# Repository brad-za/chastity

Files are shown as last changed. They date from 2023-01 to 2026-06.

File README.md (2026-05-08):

# Chastity Keyboard - Choc v1

A wireless split ergonomic keyboard featuring Kailh Choc v1 low-profile switches, rotary encoders, and ZMK firmware.

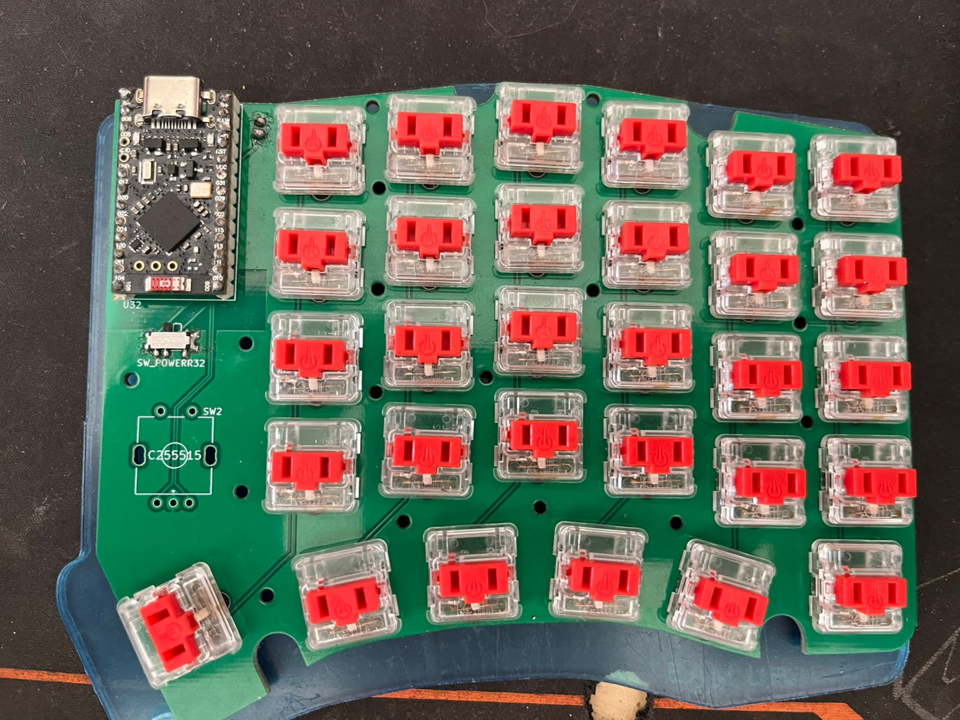
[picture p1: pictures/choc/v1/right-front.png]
Chastity Keyboard_ChocV1


## Features

- **Split Design**: Ergonomic 30-key split layout per half (60 keys total)
- **Wireless**: Powered by nice!nano v2 controllers with ZMK firmware
- **Low Profile**: Kailh Choc v1 switches for a sleek, portable design
- **Rotary Encoders**: One encoder per half for volume/scroll control
- **Hot-swap**: Choc v1 hot-swap sockets for easy switch replacement
- **Battery Powered**: Individual LiPo batteries for each half
- **Power Management**: Individual power switches per half

## Bill of Materials (BOM)

### Electronics & Controllers
| Component | Quantity | Description | Notes |
|---|---|---|---|
| nice!nano v2 | 2 | Wireless microcontroller | One per half |
| LiPo Battery | 2 | 3.7V 110-301230 or similar | ~110mAh recommended |
| JST PH 2-pin Connector | 2 | Battery connector | For nice!nano battery connection |

### Switches & Keycaps
| Component | Quantity | Description | Notes |
|---|---|---|---|
| Kailh Choc v1 Switches | 60 | Low-profile mechanical switches | Any Choc v1 variant |
| Choc v1 Keycaps (1u) | 54 | Standard 1u keycaps | |
| Choc v1 Keycaps (1u) | 2 | Indexed 1u keycaps | F & J keys |
| Choc v1 Keycaps (1.25u) | 2 | Pinky key keycaps | For control buttons cluster |
| Choc v1 Keycaps (1.5u) | 2 | Thumb key keycaps | For thumb cluster |

### Electronic Components
| Component | Quantity | Description | Package | Notes |
|---|---|---|---|---|
| Diodes | 60 | 1N4148W or similar | SOD-123 | One per switch |
| Rotary Encoder | 2 | Alps EC11E series | Through-hole | With push switch |
| Power Switch | 2 | SPDT slide switch | PCM12 package | Individual power control |
| Choc v1 Hot-swap Sockets | 60 | Kailh hot-swap sockets | | One per switch position |

### PCBs & Hardware
| Component | Quantity | Description | Notes |
|---|---|---|---|
| Chastity PCB Left | 1 | Main PCB for left half | Fabricate from KiCad files |
| Chastity PCB Right | 1 | Main PCB for right half | Fabricate from KiCad files |
| Case Components | 1 set | Laser-cut case files | Optional - see cases/choc/v1/ |

### Optional Components
| Component | Quantity | Description | Notes |
|---|---|---|---|
| USB-C Cable | 2 | Charging/programming | Standard USB-C cables |

## Assembly Instructions

### 1. PCB Preparation
1. Inspect PCBs for any manufacturing defects
2. Clean flux residue if necessary

### 2. SMD Component Soldering
1. **Diodes**: Solder all 60 diodes (30 per PCB) in SOD-123 packages
   - Pay attention to polarity markings on the PCB
   - Cathode (marked end) should align with the line on the PCB silkscreen

### 3. Through-hole Components
1. **Hot-swap sockets**: Install all 60 Choc v1 hot-swap sockets
   - Ensure proper alignment before soldering
   - Apply flux for clean joints
2. **Rotary encoders**: Install one Alps EC11E encoder per PCB
   - Ensure proper seating before soldering
3. **Power switches**: Install PCM12 slide switches
4. **Battery connectors**: Install JST PH 2-pin connectors

### 4. Controller Installation
1. **Socket installation** (recommended):
   - Install mill-max sockets for nice!nano controllers
   - This allows for easy removal/replacement
2. **nice!nano mounting**:
   - Install nice!nano v2 controllers with components facing down
   - Ensure proper pin alignment

### 5. Switch Installation
1. Install Kailh Choc v1 switches into hot-swap sockets
2. Ensure switches are fully seated and secure
3. Test each switch for proper actuation

### 6. Keycap Installation
1. Install keycaps on all switches
2. Use 1.25u keycaps for thumb cluster keys

## Firmware

This keyboard uses ZMK firmware with configurations located in `code/zmk/`.

### Flashing Firmware

#### Initial Setup
1. Connect nice!nano via USB-C
2. Put controller in bootloader mode (double-tap reset)
3. Flash the appropriate firmware:
   - `chastity_left-nice_nano_v2-zmk.uf2` for left half
   - `chastity_right-nice_nano_v2-zmk.uf2` for right half

#### Building Custom Firmware
1. Fork the ZMK config repository
2. Modify keymap in `config/chastity.keymap`
3. GitHub Actions will automatically build firmware
4. Download and flash the generated `.uf2` files

### Keymap Configuration

The keymap lives at `code/zmk/boards/shields/chastity/chastity.keymap`. Four layers are defined:

| # | Name | Purpose |
|---|---|---|
| 0 | DEFAULT  | QWERTY base layer. |
| 1 | NUMPAD | F-keys on the top row, numpad cluster on the right hand, shifted-symbol cluster on the left. Toggle with `tog NUMPAD`. |
| 2 | NAV | Caps Lock + media controls on the top-left, arrow / Home / End cluster on the right hand, **Bluetooth controls on the top-right row**. Toggle with `tog NAV`. |
| 3 | GAMING | Shifts the left half one column to the right so physical WASD outputs ESDF; the now-blank inner column gets right-side letters (P / L / M / O / I / U) so the right hand isn't needed while gaming. Toggle with the chord **RCTRL + RET (right thumb) + P**. |

#### Encoders

| Encoder | Rotation | Press (matrix-shared with the inner thumb key) |
|---|---|---|
| Left | Mouse scroll wheel up / down | `F24` — useful for binding push-to-talk or stream macros |
| Right | Volume up / down | `C_MUTE` |

The encoder press position shares its matrix net with the inner-thumb key on each half — so pressing the inner thumb fires the same key as the encoder click.

#### Bluetooth controls (on NAV layer, top-right row, inner → outer)

```
out OUT_TOG | bt BT_SEL 0 | bt BT_SEL 1 | bt BT_SEL 2 | bt BT_SEL 3 | bt BT_CLR
```

- `OUT_TOG` toggles output between USB and BLE
- `BT_SEL 0..3` switches between four paired hosts
- `BT_CLR` clears the bond on the currently selected profile (use this to re-pair). Placed at the outer edge so it isn't pressed by accident.

#### BLE name

The keyboard advertises as **`Chastity`** (set in `Kconfig.defconfig`). The right half advertises as `Chastity Right` to the central only — your host never sees it.

## Case Options

Case files are available in the `cases/choc/v1/` directory:
- `chastity-bottom-left.dxf` / `chastity-bottom-right.dxf` - Bottom plates
- `chastity-bb-left.dxf` / `chastity-bb-right.dxf` - Switch plates

### Case Assembly
1. Laser cut case components from 3mm acrylic or similar
2. Use M3 standoffs and screws for assembly
3. Install rubber feet for stability

## Suppliers & Part Numbers

### Electronics
- **nice!nano v2**: [Typeractive](https://typeractive.xyz/products/nice-nano), [splitkb.com](https://splitkb.com)
- **Batteries**: Search for "110mAh 3.7V LiPo" on electronics suppliers
- **Diodes**: 1N4148W from Digikey, Mouser, LCSC
- **Encoders**: Alps EC11E15244G1 or similar

### Mechanical Components
- **Choc v1 Switches**: [NovelKeys](https://novelkeys.com), [splitkb.com](https://splitkb.com)
- **Choc Keycaps**: [MBK keycaps](https://mkultra.click/mbk-choc-keycaps), [splitkb.com](https://splitkb.com)
- **Hot-swap Sockets**: Kailh Choc v1 sockets from mechanical keyboard suppliers

### PCB Fabrication
Upload the Gerber files from `kicad/choc/v1/` to:
- **JLCPCB**: Cost-effective option
- **PCBWay**: Good quality and service
- **OSH Park**: US-based, high quality

## Troubleshooting

### Common Issues
1. **Switch not registering**: Check diode polarity and solder joints
2. **Encoder not working**: Verify encoder orientation and pin connections
3. **Battery not charging**: Check JST connector polarity and nice!nano installation
4. **Wireless connection issues**: Re-pair devices, check ZMK configuration

### Support
- Check ZMK documentation: [zmk.dev](https://zmk.dev)
- Review schematic files in `kicad/choc/v1/`
- Verify component placement against PCB silkscreen

## License

This project is open source. PCB designs, case files, and firmware configurations are available for personal and educational use.

## Changelog

### v1.0
- Initial release with Choc v1 support
- ZMK firmware configuration
- Complete build documentation

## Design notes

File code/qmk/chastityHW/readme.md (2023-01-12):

# chastity

chastity

*A short description of the keyboard/project*

* Keyboard Maintainer: [streetRAT](https://github.com/yourusername)
* Hardware Supported: *The PCBs, controllers supported*
* Hardware Availability: *Links to where you can find this hardware*

Make example for this keyboard (after setting up your build environment):

    make chastity:default

Flashing example for this keyboard:

    make chastity:default:flash

See the [build environment setup](https://docs.qmk.fm/#/getting_started_build_tools) and the [make instructions](https://docs.qmk.fm/#/getting_started_make_guide) for more information. Brand new to QMK? Start with our [Complete Newbs Guide](https://docs.qmk.fm/#/newbs).

## Bootloader

Enter the bootloader in 3 ways:

* **Bootmagic reset**: Hold down the key at (0,0) in the matrix (usually the top left key or Escape) and plug in the keyboard
* **Physical reset button**: Briefly press the button on the back of the PCB - some may have pads you must short instead
* **Keycode in layout**: Press the key mapped to `RESET` if it is available

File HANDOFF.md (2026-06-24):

# Chastity v1 Keyboard — Firmware Debug Handoff

**Status: keyboard is unusable. Multiple symptoms, multiple failed fix attempts. Previous agent chased symptoms, did not pin down root causes. Hand-off written 2026-05-08 by previous agent who is being fired by the user.**

---

## Read me first

You are picking up a partially-failed debug session. The previous agent (me) made things worse over the course of ~6 hours of iteration. The user is exhausted, angry, and rightly out of patience. They want **root-cause analysis with verification**, not more guessing.

**Before you change a single config file:**
1. Read this entire document
2. Run the verification commands at the bottom to confirm current build state
3. Run the **hardware diagnostic checklist** in §6 — most of those should have been done before any firmware edits
4. Only then propose changes, and verify the *built artifacts* (not just the source) before asking the user to flash

The user has explicitly said "stop fixing symptoms and find the cause." Do that.

---

## §1. Hardware context

- **Board**: chastity v1 split keyboard (choc switches), user-designed PCB
- **Controllers**: 2× nice!nano v2 (nRF52840), one per half
- **Diodes**: installed **backwards by mistake** during assembly. Firmware compensates via `diode-direction = "col2row"` (NOT the upstream `row2col`). User confirmed this verbally — do not suggest reverting the direction.
- **User-verified hardware facts** (per multimeter): continuity is consistent across both halves, diodes orient consistently. User had one of two pro micros that performed worse — swap to the other did not fix anything, ruling out single-MCU damage.

### Pin layout (right half — `chastity_right.overlay`)

| Net | GPIO | nRF52840 pin | Notes |
|---|---|---|---|
| C0 (encoder col, transform col 7) | `gpio1 6` | P1.06 | only used at row 3 (encoder press) |
| C1 (transform col 8 — innermost finger col, 6/Y/H/N/RET) | `gpio0 8` | P0.08 | **default UART0 RX** |
| C2 (transform col 9 — 7/U/J/M/DEL) | `gpio0 6` | P0.06 | **default UART0 TX** |
| C3 (transform col 10 — 8/I/K/COMMA/PLUS) | `gpio1 15` | P1.15 | |
| C4 (transform col 11 — 9/O/L/DOT/NUMPAD-tog) | `gpio1 13` | P1.13 | **default SPI1 SCK** |
| C5 (transform col 12 — 0/P/SEMI/FSLH/ESC) | `gpio1 11` | P1.11 | **default SPI1 MISO** |
| C6 (transform col 13 — MINUS/RBKT/SQT/RSHFT/RCTRL) | `gpio0 10` | P0.10 | **NFC2 by default** |
| R0 (top row) | `gpio1 0` | P1.00 | |
| R1 | `gpio0 24` | P0.24 | |
| R2 | `gpio0 22` | P0.22 | |
| R3 | `gpio0 9` | P0.09 | **NFC1 by default** |
| R4 (bottom) | `gpio0 2` | P0.02 | |

### Pin layout (left half — `chastity_left.overlay`)

Different physical pins. Notable ones:
- R0 (top, used by 1-5/`~`) = `gpio0 9` = **P0.09 = NFC1**
- R3 = `gpio0 20` = default I2C0 SCL
- R4 (bottom) = `gpio0 17` = default I2C0 SDA
- R1 = `gpio1 13` = default SPI1 SCK

Left side does NOT use P0.06 / P0.08 / P0.10 / P1.11.

---

## §2. Symptoms (current, as of last user report)

After previous agent's attempted Step 3 fix (build at 09:30 today, see §4 timeline):

1. **Right half cols 8 and 9 silent** — keys `6 7 y u h j n m` and the inner two thumb keys (RET, DEL) produce nothing when pressed.
2. **Row 2 ↔ Row 3 doubling on the right half** — pressing K fires K **and** COMMA. Pressing COMMA fires K **and** COMMA. Same for L/DOT, and per the user "the whole bottom half" — so likely all (R2C, R3C) pairs across cols 10–13 double.
3. **Right encoder press fires `&kp A`** instead of the keymap-bound `&kp C_MUTE`. `A` lives at RC(2,1) — that's *the LEFT half's* matrix space. For a right-side event to land there, col-offset math doesn't work; the only explanation is that the right encoder switch is **electrically wired into the LEFT MCU's matrix at (row 2, col 1)** on the PCB. Hardware quirk; not firmware-fixable without breaking the keymap.
4. **Wireless mode produces "everywhere" wrong outputs** — user said "when in wireless mode the buttons are fucking everywhere, its like we haven't got the keymap to sit right on all the buttons." This is a NEW data point that the previous agent did not investigate. May be symptom of something deeper (timing? BLE peripheral matrix transmission?).

### Fixed (or partially fixed) earlier in the session

5. **N0 chatter spamming zeros** — improved after NFC fix (still some chatter possibly mechanical).
6. **`]` (RBKT) intermittent** — improved after NFC fix.
7. **Phantom presses on left top row** — improved after NFC fix.
8. **Stuck modifier / right-click everywhere** — improved after NFC fix (was likely RCTRL on right col 13 = `gpio0 10` = NFC2 floating high).

---

## §3. Hypotheses (with honest confidence)

### Symptom 1 (cols 8/9 dead) — Hypothesis: bootloader leaves UARTE0.PSEL configured

The Adafruit nRF52 bootloader (which nice!nano ships with) initializes UARTE0 for its own debug UART during bootloader runtime. On handoff to the application, `UARTE0.PSEL.TXD` and `PSEL.RXD` may remain bound to P0.06 and P0.08. Once the peripheral has those PSELs set in hardware, those pins are mux-locked to UARTE — kscan can't drive them as outputs.

The documented Zephyr fix is `NRF_PSEL_DISCONNECTED` pinctrl override on `uart0`, with `status = "okay"` and `CONFIG_SERIAL=y` so the UART driver compiles in and applies the disconnect at init.

**Previous agent attempted this twice and failed both times** (see §4). The second attempt actually had `CONFIG_SERIAL=y` resolving and the disconnect pinctrl present in built artifacts (verified), but per user report it made things worse rather than fixing cols 8/9.

**Confidence the bootloader-UART theory is correct: medium.** It's a documented mechanism, but the second fix attempt should have worked according to the docs and didn't. There's something we're missing.

**Alternatives unexplored:**
- A SYS_INIT C shim that calls `nrf_uarte_disable(NRF_UARTE0)` and writes `0xFFFFFFFF` to PSEL.TXD/RXD directly, before any other driver init. More forceful; bypasses Zephyr's pinctrl framework.
- Maybe `gpio0 6` and `gpio0 8` are damaged on the user's MCUs (unlikely — both MCUs swapped behave the same, both pins fail symmetrically).

### Symptom 2 (R2 ↔ R3 doubling) — Hypothesis: rows electrically shorted on right MCU

If `gpio0 22` (R2) and `gpio0 9` (R3) are connected — anywhere — then driving any column high causes both row inputs to read high simultaneously. Symptoms match exactly: pressing one switch on R2 fires its R2 binding AND the R3 binding for the same column.

**This was never tested with a multimeter.** Test: with chip powered off, probe the R2 net and R3 net at any switch on the right half. If they read continuity (≈0 Ω), the rows are shorted. Likely culprits:
- Solder bridge between P0.22 and P0.09 castellated pads on the nice!nano
- PCB trace short between the two row nets
- A diode that's mounted across the wrong two pads (bridging rows instead of going from a column to a row)

**Confidence: high that R2 and R3 are shorted given the symmetric symmetric doubling pattern.** The fact that it persists after settings reset and across power cycles rules out firmware state. The fact that it appears to span the whole bottom half (per user's "for the whole bottom half" wording) is exactly what a row-row short would produce.

### Symptom 3 (right encoder = `a`) — Hypothesis: encoder switch wired to LEFT MCU

`A` is at RC(2,1) which is left half. For right-side input to fire there, the event must originate from the left MCU's kscan, not the right's. The right encoder's switch must therefore be electrically connected to the left MCU's pins for (row 2, col 1) — either the inter-half wiring routes encoder switches centrally, or there's a PCB-design quirk where right encoder pads route to left MCU pins.

**Hardware design quirk; not firmware-fixable** without keymap gymnastics that would break standard QWERTY input.

### Symptom 4 (wireless = "everywhere") — Hypothesis: ???

Previous agent did not investigate. Worth understanding before any further changes. Possibilities:
- BLE peripheral packetizes matrix events differently and reveals a timing/race issue masked by USB
- BLE mode triggers different USB/power state that affects pin behavior
- User has multiple devices paired and is hitting wrong target

User report should be re-elicited: "wireless mode" — does that mean USB unplugged, BLE only? Tested with what host? After last flash specifically?

---

## §4. Session timeline (what was tried, why it failed)

For context. Starting state was a working-but-flawed firmware from 2026-05-07 (yesterday's first flash).

| Time | Change | Result |
|---|---|---|
| Yesterday | Initial firmware. `&uart0/&i2c0/&spi1` enabled (defaults), no NFC release. | Col 2 dead, N0/`]` dead/chattering, encoder→`a`, mouse weirdness. |
| ~21:00 | Added `&uart0 { status = "disabled" };` etc to `chastity.dtsi`. | "Big improvement" per user — N0 and `]` came back, but col 2 still dead, K-COMMA doubling still present. |
| ~21:30 | **Failed attempt #1**: `&uart0 { status = "okay" };` + `NRF_PSEL_DISCONNECTED` pinctrl, but `CONFIG_SERIAL` was not set. | Bricked both halves — `status = "okay"` with no driver bound caused phantom-press chaos. Reverted. |
| ~22:00 | Reverted to simple `status = "disabled"` form. | Back to "big improvement" baseline. |
| ~late | User reported BOTH halves were broken even on the reverted firmware. **Crucial data point**: this elevated NFC-pins-as-GPIOs to a new prime suspect. |
| **09:02 today** | Added `&uicr { nfct-pins-as-gpios; };` to release P0.09/P0.10 from NFC mode. Verified compile flags `-DCONFIG_NFCT_PINS_AS_GPIOS` present in built artifacts. | User reported "definite improvement" after flashing — phantom presses cleared, mouse weirdness gone. Cols 8/9 still dead. K-COMMA / L-DOT doubling still present. |
| **09:23 today** | **Failed attempt #2 (silent)**: tried Step 3 again. Added `CONFIG_SERIAL=y` to `chastity.conf`. Did NOT verify in built `.config`. | After build, `# CONFIG_SERIAL is not set` in `.config` because **`chastity.conf` is NOT merged at build time** in user-config builds; only `chastity_left.conf` and `chastity_right.conf` are merged. The DT had `uart0 status="okay"` with no driver again — **same brick condition as attempt #1**. |
| **09:30 today** | **Failed attempt #3**: moved `CONFIG_SERIAL=y` into `chastity_right.conf` and `chastity_left.conf`. Verified `CONFIG_SERIAL=y`, `CONFIG_UART_NRFX_UARTE=y`, and disconnect psels in built `zephyr.dts`. | User flashed; reports things got WORSE — "buttons everywhere in wireless mode," symptoms 1-4 above. Why this fix didn't work: **unknown**. The artifacts looked correct. Either the Zephyr UARTE legacy shim isn't doing what we expect, or there's a different mechanism at play. |

The user's keyboard right now is running the 09:30 firmware (worst state). They did not flash the rollback yet.

---

## §5. CRITICAL: build/flash file location confusion (we lost time on this)

There are **two locations** for UF2s and **the build doesn't auto-sync them**:

- **A**: `code/zmk/build/{left,right}/zephyr/zmk.uf2` — where `west build` writes
- **B**: `firmware/choc/v1/zmk-build/chastity_{left,right}.uf2` — where the user flashes from in Finder

Previous agent did not realize this for several hours. User was repeatedly flashing yesterday's stale firmware from B while the agent insisted "I just built new firmware" referring to A. Most of last night's symptom reports may have been from yesterday's firmware, not whatever the agent had built.

A build helper script was added at `code/zmk/build.sh` that builds + copies to B in one shot. **Use it.** Do not run `west build` directly.

```bash
cd /workspaces/chastity/code/zmk
./build.sh both       # builds both halves, copies to firmware/
./build.sh right      # right only
./build.sh left       # left only
```

After a build, **always** verify the firmware folder timestamps before telling the user to flash:
```bash
ls -la /workspaces/chastity/firmware/choc/v1/zmk-build/
```
If the date is not "today, recent minutes," the build did not copy successfully and you must investigate.

---

## §6. Hardware diagnostic checklist (DO THIS FIRST)

The previous agent never asked the user to do these. Most are 30-second multimeter tests. Do them before changing any code.

### A. Row 2 ↔ Row 3 short on right (Symptom 2 root cause hypothesis)

**Test**: with right half powered off, probe the R2 net (P0.22 on the right MCU castellated pad) and the R3 net (P0.09 on the right MCU). Measure resistance.

- If <10 Ω: rows are shorted. Find the short — likely a solder bridge on the MCU castellated pads, a diode mounted across the wrong pads, or a PCB trace defect. Once removed, K-COMMA doubling will stop. Symptoms 1 and 4 may also be related.
- If >1 MΩ: rows are not shorted; doubling has a different cause. Continue investigation.

### B. Cols 8/9 actually responding to drive (Symptom 1)

**Test**: with right half powered ON and running current firmware, probe `gpio0 6` (P0.06) and `gpio0 8` (P0.08) on the right MCU castellated pads. Use scope or fast multimeter.

- If voltage stays at one fixed level (always low or always high) regardless of which key column is being driven: the pins are not being driven by kscan. Either UART peripheral has hold (matches bootloader-UART theory) or the pins are damaged.
- If voltage pulses high during scan cycles: pins are working, problem is elsewhere (bad column trace, etc.).

### C. Right encoder switch — where is it actually wired (Symptom 3)

**Test**: with chip powered off, ohm out the right encoder's two switch terminals against:
- Every left MCU castellated pad
- Every right MCU castellated pad

Find which two pads it connects between. Map those to the matrix R/C of whichever MCU's pads they are. The keymap binding for that physical (R, C) is what the encoder press will fire.

### D. Wireless vs wired behavior diagnostic (Symptom 4)

**Test**: flash the same firmware. Connect right half over USB; type test pattern (`123 qwe asd zxc 67890 yuiop hjkl; nm,./`). Then unplug USB, run on battery, BLE-connect to host; type the same pattern. Compare outputs.

If outputs differ between USB and BLE modes, that's important new information. The cause needs investigation; previous agent has no theory.

### E. NFC UICR programming actually completed

**Test**: requires `nrfjprog` (Nordic command-line tool). With one half connected via SWD/J-Link (not USB):
```
nrfjprog --memrd 0x1000120C --n 4
```
- If returns `FFFFFFFF`: NFCPINS is set to "GPIO mode" — programming completed.
- If returns `FFFFFFFE` (or anything else): NFCPINS still in "NFC reserved" mode — UICR programming did not happen, and the NFC fix never took effect.

If the user doesn't have a J-Link / nrfjprog setup, they may need to. Or skip this test and trust that the firmware boot-time UICR write worked (system_nrf52.c does this when `CONFIG_NFCT_PINS_AS_GPIOS` is defined, which we verified is in the compile flags).

---

## §7. File state at handoff

```bash
git status code/zmk/boards/shields/chastity/ code/zmk/firmware/ firmware/
```

The following files have uncommitted changes from this session:

- `code/zmk/boards/shields/chastity/chastity.dtsi` — has both the `&uicr { nfct-pins-as-gpios; };` AND the `NRF_PSEL_DISCONNECTED` UART pinctrl override AND `&uart0 { status = "okay" };` AND `&i2c0/&spi1 { status = "disabled" };`. Per §4 timeline, this is the 09:30 broken-state source. Flashed firmware reflects this.
- `code/zmk/boards/shields/chastity/chastity.conf` — back to original `EC11/POINTING` only. (Note: this file is **not merged** in user-config builds.)
- `code/zmk/boards/shields/chastity/chastity_left.conf` — was empty originally, may now have `CONFIG_SERIAL=y` etc. or may be empty (previous agent was reverting at the time of handoff).
- `code/zmk/boards/shields/chastity/chastity_right.conf` — same as above.
- `code/zmk/build.sh` — new helper script (use this for builds).

The firmware folder `firmware/choc/v1/zmk-build/` has the 09:30 broken UF2s flashed into it.

**Recommended baseline before further work**:
1. `git checkout code/zmk/boards/shields/chastity/` to reset all source files
2. Manually re-add ONLY the `&uicr { nfct-pins-as-gpios; };` line to `chastity.dtsi` (this is the one fix that survived testing — user reported "definite improvement")
3. Build: `cd code/zmk && ./build.sh both`
4. Verify in built artifacts:
   - `grep "nfct-pins-as-gpios" build/right/zephyr/zephyr.dts` should return the property
   - `grep "DT_HAS_NORDIC_NRF_UICR" build/right/zephyr/include/generated/zephyr/devicetree_generated.h | head` should show the UICR node configured
5. User can flash that as a "known-decent" baseline

---

## §8. What the previous agent got wrong (so you don't repeat)

1. **Said "90% confident this fixes it" before verifying.** Don't claim confidence until artifacts are checked end-to-end.
2. **Didn't verify built `.config` and `zephyr.dts` for the first Step 3 attempt.** Source had `CONFIG_SERIAL=y` but it wasn't merged. Always grep the *built* `.config` for the symbol you set, not just the conf file.
3. **Conflated `code/zmk/build/` and `firmware/`.** User was flashing stale builds for hours.
4. **Cargo-culted the `NRF_PSEL_DISCONNECTED` pattern** before understanding *why* it works (driver init writes the disconnect; requires the driver to compile in).
5. **Never asked the user to multimeter R2-R3 directly.** That single test would have been a faster path to the K-COMMA doubling root cause than three rebuild iterations.
6. **Updated memory with declarations of victory** before they were proven (e.g., the diode-direction note didn't mention "but this surfaces other latent issues too").
7. **Made one-line fix proposals when the system was complex.** This codebase has at least 4 interacting layers (diodes, peripheral pinctrl, NFC UICR, keymap) and any of them can mask another. Fix one at a time, test in isolation.
8. **Continued making firmware changes when the user said "stop fixing symptoms and find the cause."** Listen.

---

## §9. References (sourced docs that the agent confirmed)

- [ZMK Zephyr 4.1 Update — NFC pin migration to `&uicr { nfct-pins-as-gpios; };`](https://zmk.dev/blog/2025/12/09/zephyr-4-1)
- [Zephyr 3.5 migration guide — `nfct-pins-as-gpios`](https://docs.zephyrproject.org/latest/releases/migration-guide-3.5.html)
- [Zephyr `nordic,nrf-pinctrl` binding (NRF_PSEL_DISCONNECTED)](https://docs.zephyrproject.org/latest/build/dts/api/bindings/pinctrl/nordic,nrf-pinctrl.html)
- [Zephyr issue #27080 — UARTE PSEL must be set with peripheral disabled](https://github.com/zephyrproject-rtos/zephyr/issues/27080)
- [Nordic DevZone — pinctrl pins remain connected after omission](https://devzone.nordicsemi.com/f/nordic-q-a/93574/pinctrl-configuration)
- [Adafruit nRF52 Bootloader changelog](https://github.com/adafruit/Adafruit_nRF52_Bootloader/blob/master/changelog.md)
- [ZMK Debouncing docs](https://zmk.dev/docs/features/debouncing)
- [Zephyr nRF SoC Kconfig — `NFCT_PINS_AS_GPIOS` (still defined for nrfx HAL pickup despite the user-facing Kconfig being removed)](https://github.com/zephyrproject-rtos/zephyr/blob/main/soc/nordic/Kconfig)

---

## §10. Build / verify commands cheat sheet

```bash
# Full clean build of both halves
cd /workspaces/chastity/code/zmk
./build.sh both

# Verify CONFIG values in built artifacts (right half — same path for left)
grep "^CONFIG_SERIAL\|^CONFIG_NRFX_UARTE\|^CONFIG_NFCT" build/right/zephyr/.config
grep "^CONFIG_UART_NRFX" build/right/zephyr/.config

# Verify DT changes landed
grep -A 12 "uart0:" build/right/zephyr/zephyr.dts
grep -A 5 "uicr" build/right/zephyr/zephyr.dts
grep -A 5 "kscan0:" build/right/zephyr/zephyr.dts | grep debounce  # only if debounce was set

# Verify HAL compile flags (NFC, UART pin disconnects)
grep "NFCT_PINS_AS_GPIOS\|UART" build/right/build.ninja | head -2

# Verify firmware/ folder up to date
ls -la /workspaces/chastity/firmware/choc/v1/zmk-build/
md5sum build/right/zephyr/zmk.uf2 /workspaces/chastity/firmware/choc/v1/zmk-build/chastity_right.uf2
```

```bash
# User flashes from /workspaces/chastity/firmware/choc/v1/zmk-build/ via Finder
# Sequence per ZMK:
# 1. settings_reset.uf2 onto each half (clears BLE bonds + persisted state)
# 2. chastity_left.uf2 onto left, chastity_right.uf2 onto right
# 3. Power cycle both halves
# 4. Forget keyboard from host's Bluetooth, re-pair fresh
```

---

## §11. Suggested next steps for you (the new agent)

1. Read this whole document. Read `/workspaces/chastity/code/zmk/boards/shields/chastity/` source files. Read `/root/.claude/projects/-workspaces-chastity/memory/` for context the previous agent recorded.
2. **Ask the user to do hardware diagnostic A** (R2-R3 short test) before any code change. This is the single most-likely-to-be-decisive test.
3. While they do that, revert the source to a known-good baseline (NFC fix only — see §7).
4. Build and verify the baseline in built artifacts. Don't ship until checks pass.
5. Hand the user the rollback firmware first ("here's the known-OK baseline"), have them flash it, confirm symptoms are at the level they were after the 09:02 NFC build (cols 8/9 dead, K-COMMA doubling, encoder→a, but otherwise functional).
6. Now you have a clean ground truth. Proceed with diagnostic-driven fixes for each remaining symptom, one at a time, with confirmation between each.

The user wants results, not theatrics. Be terse. Don't promise; show. Verify in built artifacts before declaring a fix is "ready to flash."

Good luck.

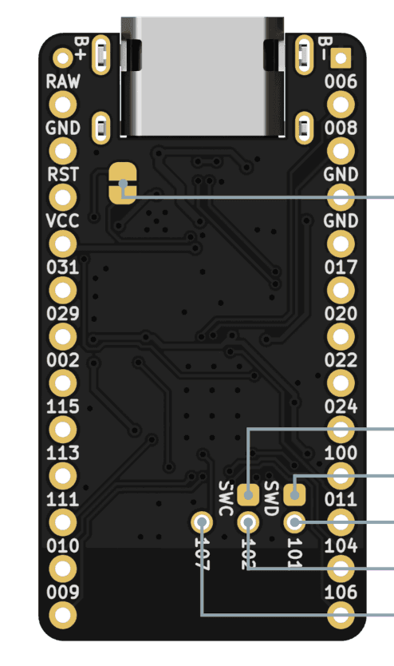
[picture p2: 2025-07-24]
pictures/dev boards/pinout-v2.2.png

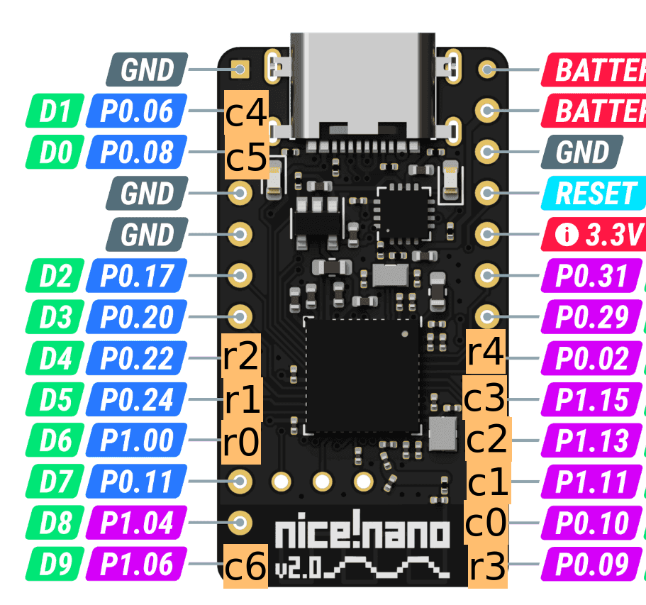
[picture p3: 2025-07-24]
pictures/dev boards/pinout-rightv2.png

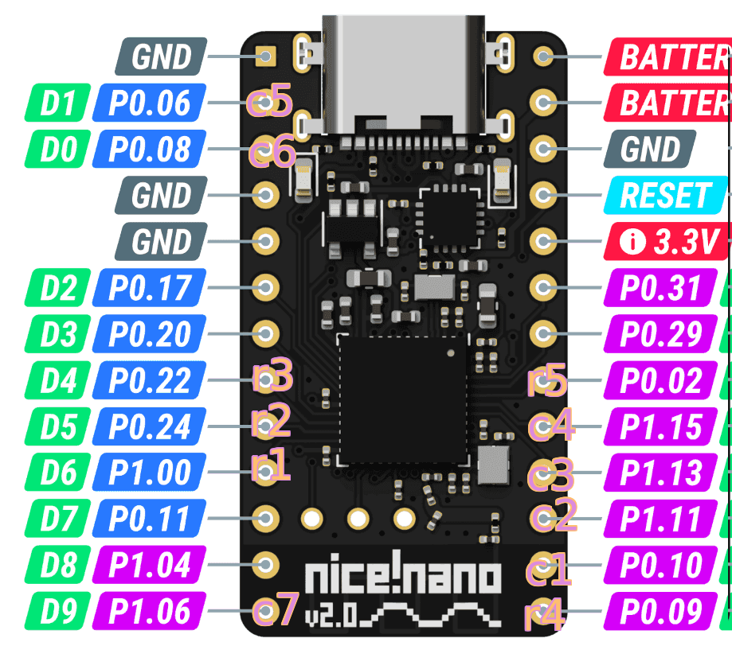
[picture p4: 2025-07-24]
pictures/dev boards/pinout-right.png

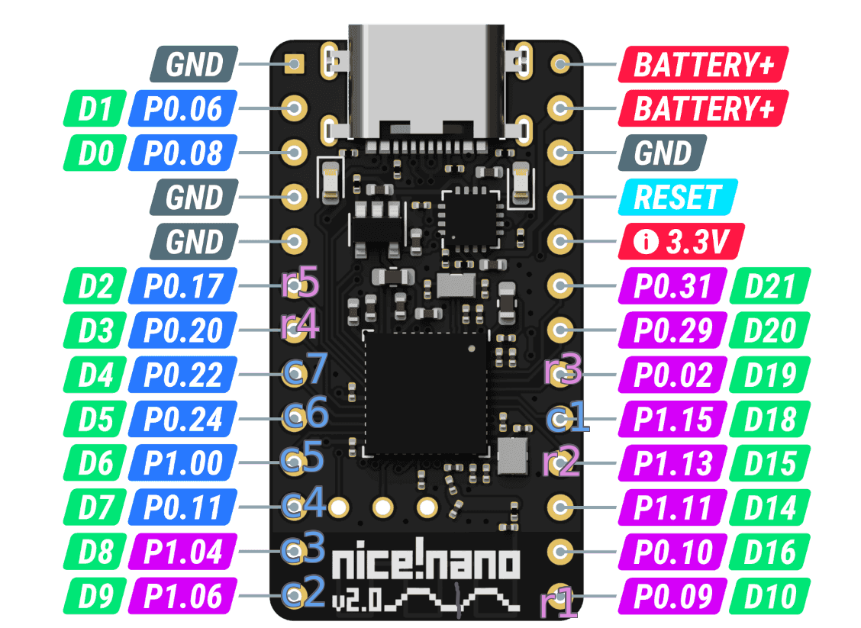
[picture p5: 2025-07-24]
pictures/dev boards/pinout-left.png

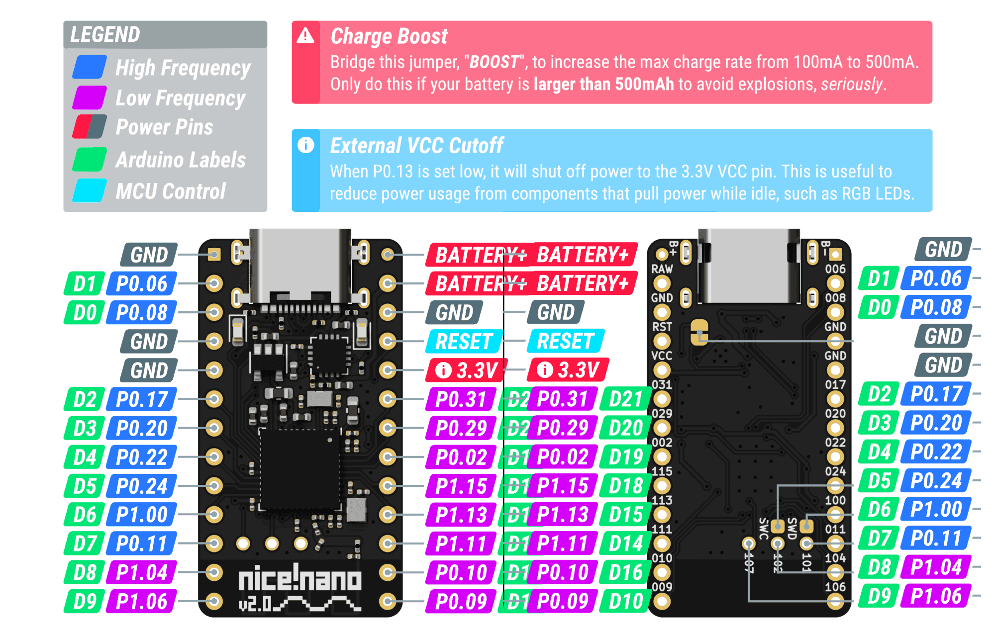
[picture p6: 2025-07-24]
pictures/dev boards/pinout-v2.png

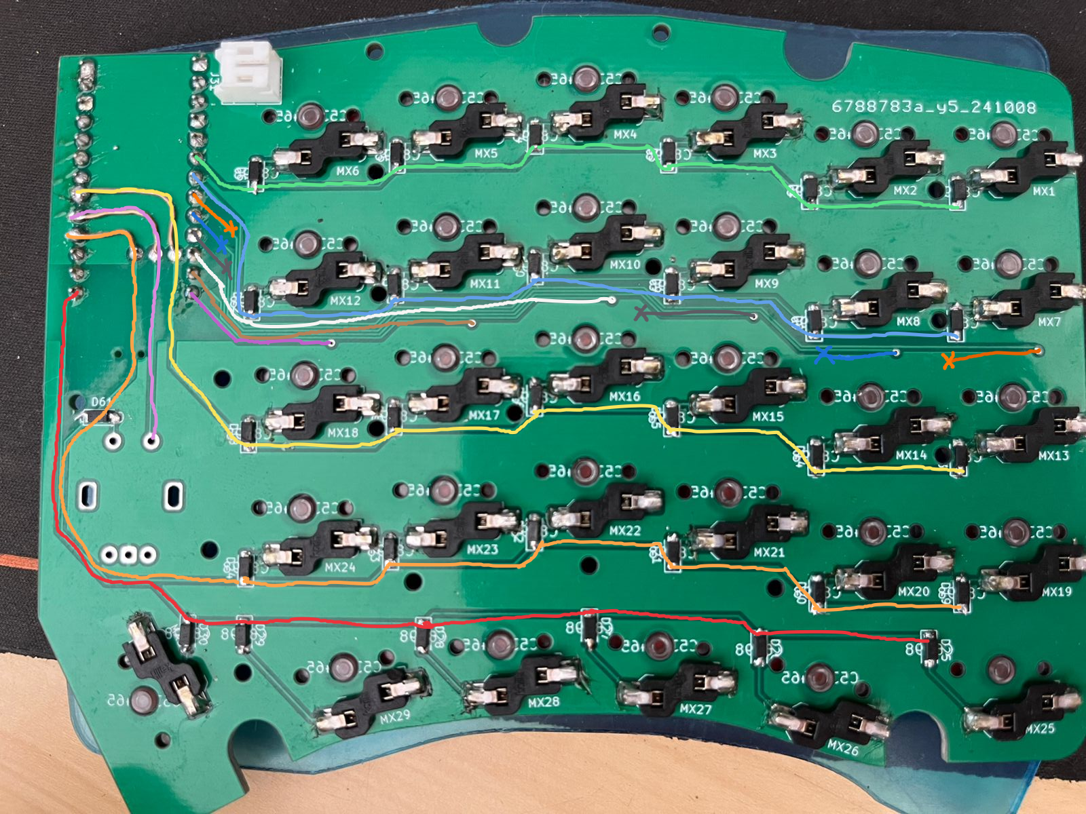
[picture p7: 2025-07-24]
pictures/choc/v1/left-back.png

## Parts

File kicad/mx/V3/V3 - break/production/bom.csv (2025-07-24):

Designator | Footprint | Quantity | Value | LCSC Part #
BOOT1, BOOT2, RST1, RST2 | SW_SPST_TL3342 | 4 | SW_Push
C1, C10, C19, C2, C21, C28, C3, C31, C32, C33 | 0402 | 10 | 1u
C11, C12, C13, C14, C15, C16, C17, C18, C22, C23, C24, C25, C26, C27, C29, C30, C35, C6 | 0402 | 18 | 100n
C20, C9 | 0603 | 2 | 10u
C34, C39, C4, C40, C41, C42, C43, C44, C45, C46, C47, C48 | 0402 | 12 | 100u
C36, C37, C5, C7 | 0402 | 4 | 22p
C38, C8 | 0402 | 2 | 100n | C1760
D1, D10, D11, D12, D13, D14, D15, D16, D17, D18, D19, D2, D20, D21, D22, D23, D24, D25, D26, D27, D28, D29, D3, D30, D31, D32, D33, D34, D35, D36, D37, D38, D39, D4, D40, D41, D42, D43, D44, D45, D46, D47, D48, D49, D5, D50, D51, D52, D53, D54, D55, D56, D57, D58, D59, D6, D60, D61, D62, D7, D8, D9 | D_SOD-123 | 62 | D_Small
F1, F2 | 1206 | 2 | Fuse_Small
J1, J4 | USB_C_Receptacle_HRO_TYPE-C-31-M-14 | 2 | USB_C_Receptacle_USB2.0
J2, J5 | PinSocket_1x05_P2.54mm_Horizontal | 2 | Conn_01x05
J3, J6 | PinHeader_1x08_P2.54mm_Horizontal | 2 | Conn_01x08_Pin
LED1, LED10, LED11, LED12, LED13, LED14, LED15, LED16, LED17, LED18, LED19, LED2, LED20, LED21, LED22, LED23, LED24, LED25, LED26, LED27, LED28, LED29, LED3, LED30, LED31, LED32, LED33, LED34, LED35, LED36, LED37, LED38, LED39, LED4, LED40, LED41, LED42, LED43, LED44, LED45, LED46, LED47, LED48, LED49, LED5, LED50, LED51, LED52, LED53, LED54, LED55, LED56, LED57, LED58, LED59, LED6, LED60, LED7, LED8, LED9 | LED_MX_6028R | 60 | SK6803MINI-E
MX1, MX10, MX11, MX12, MX13, MX14, MX15, MX16, MX17, MX18, MX19, MX2, MX20, MX21, MX22, MX23, MX24, MX25, MX26, MX27, MX28, MX29, MX3, MX30, MX31, MX32, MX33, MX34, MX35, MX36, MX37, MX38, MX39, MX4, MX40, MX41, MX42, MX43, MX44, MX45, MX46, MX47, MX48, MX49, MX5, MX50, MX51, MX52, MX53, MX54, MX55, MX56, MX57, MX58, MX59, MX6, MX60, MX7, MX8, MX9 | SW_MX_HS_1u | 60 | MX_SW_HS
R1, R10, R12, R13, R15, R16, R2, R22, R23, R24, R26, R27, R5, R7 | 0402 | 14 | 5K1
R11, R14, R25, R28 | 0402 | 4 | 1k
R17, R21, R3, R9 | 0402 | 4 | 5k1 | C27834
R18, R19, R4, R6 | 0402 | 4 | 27
R20, R8 | 0402 | 2 | 75k | C17819
S1, S31 | STAB_MX_P_2u | 2 | MX_stab
SPLIT_L1, SPLIT_R1 | USB_C_Receptacle_HRO_TYPE-C-31-M-14 | 2 | USB-C-2.0
SW1, SW2 | ROT_Alps_EC11E-Switch | 2 | RotaryEncoder_Switch
U1, U8 | SOIC-8_5.23x5.23mm_P1.27mm | 2 | W25Q128JVS
U10, U3 | QFN-56-1EP_7x7mm_P0.4mm_EP3.2x3.2mm | 2 | RP2040
U11, U6 | SOT-23-5 | 2 | 74AHC1G125
U12, U2 | SOT-23-6 | 2 | USBLC6-2SC6
U4, U9 | SOT-23-3 | 2 | XC6206PxxxMR
U5, U7 | SOT-23-6 | 2 | TPS2553DBVR | C55266
Y1, Y2 | Crystal_SMD_3225-4Pin_3.2x2.5mm | 2 | Crystal_GND24

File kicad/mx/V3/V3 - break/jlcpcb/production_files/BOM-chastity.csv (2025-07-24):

Comment | Designator | Footprint | LCSC
10u | C20,C9,J1,J4,SPLIT_L1,SPLIT_R1,U1,U4,U8,U9 | C_0603_1608Metric | C1035
5K1 | R1,R10,R11,R12,R13,R14,R15,R16,R2,R22,R23,R24,R25,R26,R27,R28,R5,R7 | R_0402_1005Metric | C11702
100n | C11,C12,C13,C14,C15,C16,C17,C18,C22,C23,C24,C25,C26,C27,C29,C30,C35,C6 | C_0402_1005Metric | C1525
22p | C36,C37,C5,C7 | C_0402_1005Metric | C1555
100n | C38,C8 | C_0402_1005Metric | C1760
75k | R20,R8 | C_0402_1005Metric | C17819
RotaryEncoder_Switch | SW1,SW2 | ROT_Alps_EC11E-Switch | C202365
RP2040 | U10,U3 | QFN-56-1EP_7x7mm_P0.4mm_EP3.2x3.2mm | C2040
27 | R18,R19,R4,R6 | R_0402_1005Metric | C25100
5k1 | R17,R21,R3,R9 | C_0402_1005Metric | C27834
SW_Push | BOOT1,BOOT2,RST1,RST2 | SW_SPST_TL3342 | C318884
MX_SW_HS | MX1,MX10,MX11,MX12,MX13,MX14,MX15,MX16,MX17,MX18,MX19,MX2,MX20,MX21,MX22,MX23,MX24,MX25,MX26,MX27,MX28,MX29,MX3,MX30,MX31,MX32,MX33,MX34,MX35,MX36,MX37,MX38,MX39,MX4,MX40,MX41,MX42,MX43,MX44,MX45,MX46,MX47,MX48,MX49,MX5,MX50,MX51,MX52,MX53,MX54,MX55,MX56,MX57,MX58,MX59,MX6,MX60,MX7,MX8,MX9 | SW_MX_HS_1u | C5184526
SK6803MINI-E | LED1,LED10,LED11,LED12,LED13,LED14,LED15,LED16,LED17,LED18,LED19,LED2,LED20,LED21,LED22,LED23,LED24,LED25,LED26,LED27,LED28,LED29,LED3,LED30,LED31,LED32,LED33,LED34,LED35,LED36,LED37,LED38,LED39,LED4,LED40,LED41,LED42,LED43,LED44,LED45,LED46,LED47,LED48,LED49,LED5,LED50,LED51,LED52,LED53,LED54,LED55,LED56,LED57,LED58,LED59,LED6,LED60,LED7,LED8,LED9 | LED_MX_6028R | C5242955
1u | C1,C10,C19,C2,C21,C28,C3,C31,C32,C33 | C_0402_1005Metric | C52923
USBLC6-2SC6 | U12,U2,U5,U7 | SOT-23-6 | C55266
Fuse_Small | F1,F2 | Fuse_1206_3216Metric | C70076
74AHC1G125 | U11,U6 | SOT-23-5 | C7484
100u | C34,C39,C4,C40,C41,C42,C43,C44,C45,C46,C47,C48 | C_0402_1005Metric | C77130
D_Small | D1,D10,D11,D12,D13,D14,D15,D16,D17,D18,D19,D2,D20,D21,D22,D23,D24,D25,D26,D27,D28,D29,D3,D30,D31,D32,D33,D34,D35,D36,D37,D38,D39,D4,D40,D41,D42,D43,D44,D45,D46,D47,D48,D49,D5,D50,D51,D52,D53,D54,D55,D56,D57,D58,D59,D6,D60,D61,D62,D7,D8,D9 | D_SOD-123 | C8598
Crystal_GND24 | Y1,Y2 | Crystal_SMD_3225-4Pin_3.2x2.5mm | C9002
~ | TFT2 | TFT 1.47 waveshare
~ | TFT1 | TFT 1.47 waveshare
MX_stab | S31 | STAB_MX_P_2u
MX_stab | S1 | STAB_MX_P_2u
Conn_01x05 | J5 | PinSocket_1x05_P2.54mm_Horizontal
Conn_01x08_Pin | J6 | PinHeader_1x08_P2.54mm_Horizontal
Conn_01x05 | J2 | PinSocket_1x05_P2.54mm_Horizontal
Conn_01x08_Pin | J3 | PinHeader_1x08_P2.54mm_Horizontal

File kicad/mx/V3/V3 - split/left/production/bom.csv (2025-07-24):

Designator | Footprint | Quantity | Value | LCSC Part #
BOOT1, RST1 | SW_SPST_TL3342 | 2 | SW_Push
C1, C10, C19, C2, C3 | 0402 | 5 | 1u
C11, C12, C13, C14, C15, C16, C17, C18, C6 | 0402 | 9 | 100n
C39, C4, C41, C43, C45, C47 | 0402 | 6 | 100u
C5, C7 | 0402 | 2 | 22p
C8 | 0402 | 1 | 100n | C1760
C9 | 0603 | 1 | 10u
D1, D10, D11, D12, D13, D14, D15, D16, D17, D18, D19, D2, D20, D21, D22, D23, D24, D25, D26, D27, D28, D29, D3, D30, D4, D5, D6, D61, D7, D8, D9 | D_SOD-123 | 31 | D_Small
F1 | 1206 | 1 | Fuse_Small
J1 | USB_C_Receptacle_HRO_TYPE-C-31-M-14 | 1 | USB_C_Receptacle_USB2.0
J2 | PinSocket_1x05_P2.54mm_Horizontal | 1 | Conn_01x05
J3 | PinHeader_1x08_P2.54mm_Horizontal | 1 | Conn_01x08_Pin
LED1, LED10, LED11, LED12, LED13, LED14, LED15, LED16, LED17, LED18, LED19, LED2, LED20, LED21, LED22, LED23, LED24, LED25, LED26, LED27, LED28, LED29, LED3, LED30, LED4, LED5, LED6, LED7, LED8, LED9 | LED_MX_6028R | 30 | SK6803MINI-E
MX1, MX10, MX11, MX12, MX13, MX14, MX15, MX16, MX17, MX18, MX19, MX2, MX20, MX21, MX22, MX23, MX24, MX25, MX26, MX27, MX28, MX29, MX3, MX30, MX4, MX5, MX6, MX7, MX8, MX9 | SW_MX_HS_1u | 30 | MX_SW_HS
R1, R10, R12, R13, R2, R5, R7 | 0402 | 7 | 5K1
R11, R14 | 0402 | 2 | 1k
R3, R9 | 0402 | 2 | 5k1 | C27834
R4, R6 | 0402 | 2 | 27
R8 | 0402 | 1 | 75k | C17819
S1 | STAB_MX_P_2u | 1 | MX_stab
SPLIT_L1 | USB_C_Receptacle_HRO_TYPE-C-31-M-14 | 1 | USB-C-2.0
SW1 | ROT_Alps_EC11E-Switch | 1 | RotaryEncoder_Switch
U1 | SOIC-8_5.23x5.23mm_P1.27mm | 1 | W25Q128JVS
U2 | SOT-23-6 | 1 | USBLC6-2SC6
U3 | QFN-56-1EP_7x7mm_P0.4mm_EP3.2x3.2mm | 1 | RP2040
U4 | SOT-23-3 | 1 | XC6206PxxxMR
U5 | SOT-23-6 | 1 | TPS2553DBVR | C55266
U6 | SOT-23-5 | 1 | 74AHC1G125
Y1 | Crystal_SMD_3225-4Pin_3.2x2.5mm | 1 | Crystal_GND24

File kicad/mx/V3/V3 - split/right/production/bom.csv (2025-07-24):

Designator | Footprint | Quantity | Value | LCSC Part #
BOOT2, RST2 | SW_SPST_TL3342 | 2 | SW_Push
C20 | 0603 | 1 | 10u
C21, C28, C31, C32, C33 | 0402 | 5 | 1u
C22, C23, C24, C25, C26, C27, C29, C30, C35 | 0402 | 9 | 100n
C34, C40, C42, C44, C46, C48 | 0402 | 6 | 100u
C36, C37 | 0402 | 2 | 22p
C38 | 0402 | 1 | 100n | C1760
D31, D32, D33, D34, D35, D36, D37, D38, D39, D40, D41, D42, D43, D44, D45, D46, D47, D48, D49, D50, D51, D52, D53, D54, D55, D56, D57, D58, D59, D60, D62 | D_SOD-123 | 31 | D_Small
F2 | 1206 | 1 | Fuse_Small
J4 | USB_C_Receptacle_HRO_TYPE-C-31-M-14 | 1 | USB_C_Receptacle_USB2.0
J5 | PinSocket_1x05_P2.54mm_Horizontal | 1 | Conn_01x05
J6 | PinHeader_1x08_P2.54mm_Horizontal | 1 | Conn_01x08_Pin
LED31, LED32, LED33, LED34, LED35, LED36, LED37, LED38, LED39, LED40, LED41, LED42, LED43, LED44, LED45, LED46, LED47, LED48, LED49, LED50, LED51, LED52, LED53, LED54, LED55, LED56, LED57, LED58, LED59, LED60 | LED_MX_6028R | 30 | SK6803MINI-E
MX31, MX32, MX33, MX34, MX35, MX36, MX37, MX38, MX39, MX40, MX41, MX42, MX43, MX44, MX45, MX46, MX47, MX48, MX49, MX50, MX51, MX52, MX53, MX54, MX55, MX56, MX57, MX58, MX59, MX60 | SW_MX_HS_1u | 30 | MX_SW_HS
R15, R16, R22, R23, R24, R26, R27 | 0402 | 7 | 5K1
R17, R21 | 0402 | 2 | 5k1 | C27834
R18, R19 | 0402 | 2 | 27
R20 | 0402 | 1 | 75k | C17819
R25, R28 | 0402 | 2 | 1k
S31 | STAB_MX_P_2u | 1 | MX_stab
SPLIT_R1 | USB_C_Receptacle_HRO_TYPE-C-31-M-14 | 1 | USB-C-2.0
SW2 | ROT_Alps_EC11E-Switch | 1 | RotaryEncoder_Switch
U10 | QFN-56-1EP_7x7mm_P0.4mm_EP3.2x3.2mm | 1 | RP2040
U11 | SOT-23-5 | 1 | 74AHC1G125
U12 | SOT-23-6 | 1 | USBLC6-2SC6
U7 | SOT-23-6 | 1 | TPS2553DBVR | C55266
U8 | SOIC-8_5.23x5.23mm_P1.27mm | 1 | W25Q128JVS
U9 | SOT-23-3 | 1 | XC6206PxxxMR
Y2 | Crystal_SMD_3225-4Pin_3.2x2.5mm | 1 | Crystal_GND24

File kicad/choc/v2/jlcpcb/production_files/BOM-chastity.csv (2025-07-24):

Comment | Designator | Footprint | LCSC
Conn_01x02_Socket | J31,J32 | JST_PH_S2B-PH-K_1x02_P2.00mm_Horizontal | C160237
SW_SPDT | SW_POWERR31,SW_POWERR32 | SW_SPDT_PCM12 | C221841
RotaryEncoder_Switch | SW1,SW2 | ROT_Alps_EC11E-Switch | C255515
MX_SW_HS | MX1,MX10,MX11,MX12,MX13,MX14,MX15,MX16,MX17,MX18,MX19,MX2,MX20,MX21,MX22,MX23,MX24,MX26,MX27,MX28,MX29,MX3,MX30,MX31,MX32,MX33,MX34,MX35,MX36,MX37,MX38,MX39,MX4,MX40,MX41,MX42,MX43,MX44,MX45,MX46,MX47,MX48,MX49,MX5,MX50,MX51,MX52,MX53,MX54,MX55,MX56,MX57,MX58,MX59,MX6,MX7,MX8,MX9 | SW_choc_v1_HS_CPG135001S30_1u | C5333465
D_Small | D1,D10,D11,D12,D13,D14,D15,D16,D17,D18,D19,D2,D20,D21,D22,D23,D24,D25,D26,D27,D28,D29,D3,D30,D31,D32,D33,D34,D35,D36,D37,D38,D39,D4,D40,D41,D42,D43,D44,D45,D46,D47,D48,D49,D5,D50,D51,D52,D53,D54,D55,D56,D57,D58,D59,D6,D60,D61,D62,D7,D8,D9 | D_SOD-123 | C8598
MX_SW_HS | MX60 | SW_choc_v1_HS_CPG135001S30_1.25u
MX_SW_HS | MX25 | SW_choc_v1_HS_CPG135001S30_1.25u

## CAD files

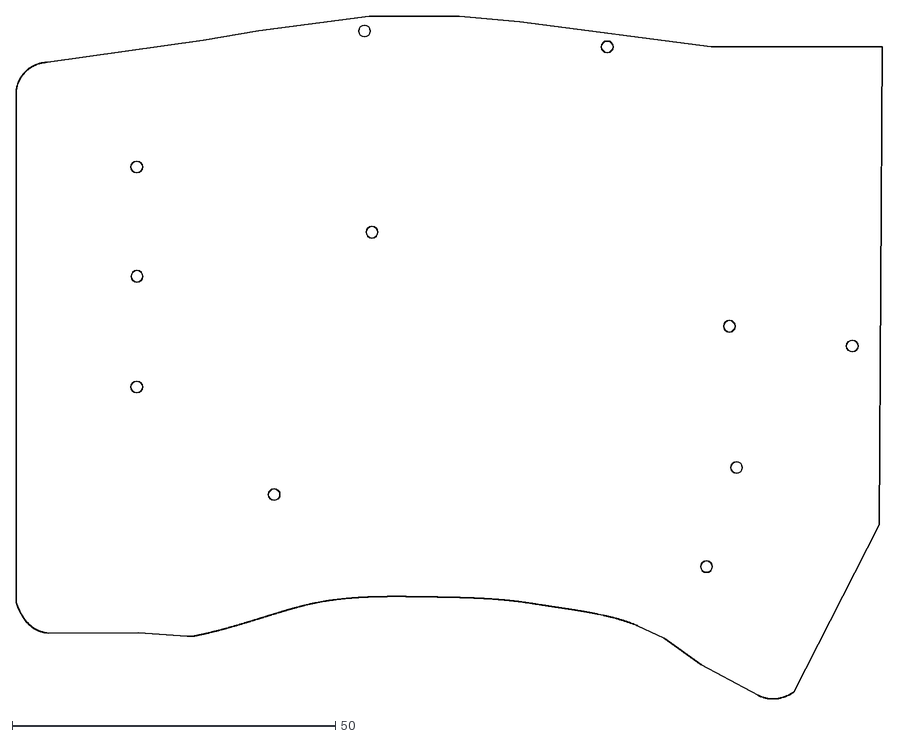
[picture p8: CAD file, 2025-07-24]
cases/choc/v1/chastity-bottom-left.dxf
134.0 x 105.7

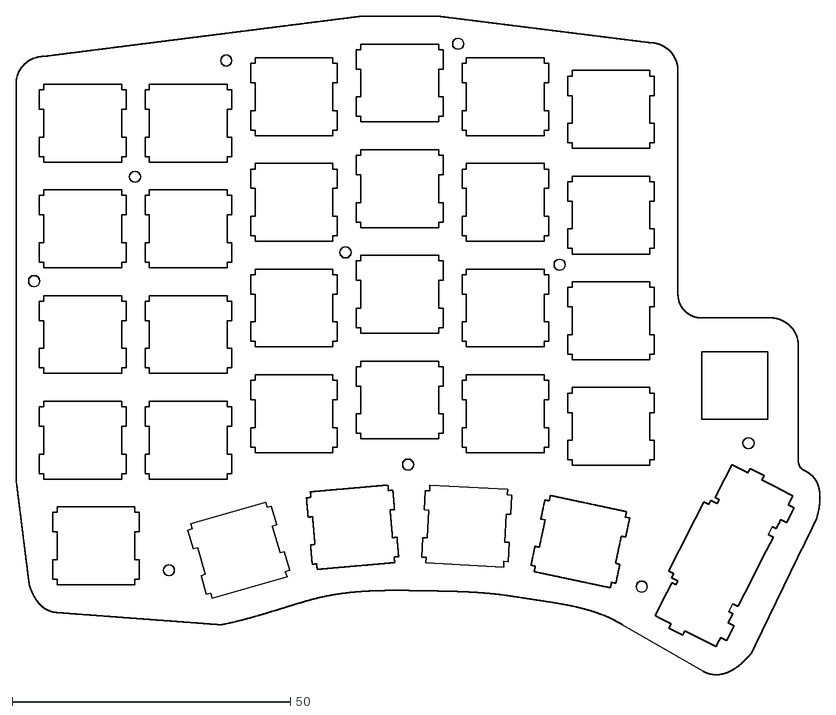
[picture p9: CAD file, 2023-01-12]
cases/HW/top.dxf
144.6 x 118.4

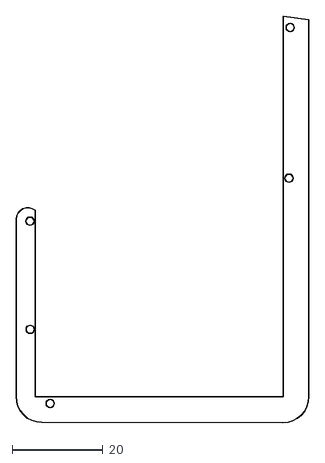
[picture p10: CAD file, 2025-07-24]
cases/choc/v1/chastity-bb-right.dxf
64.4 x 89.4

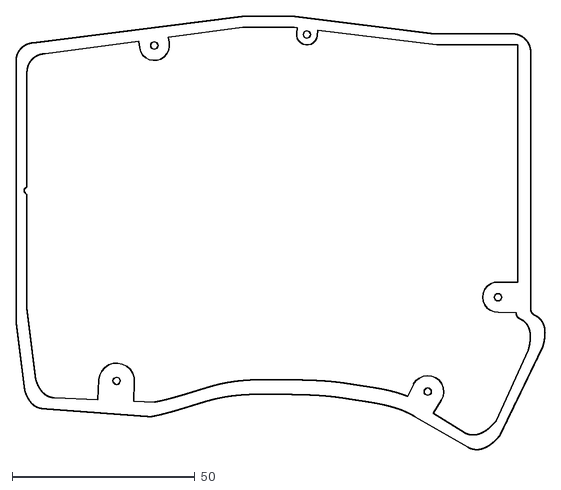
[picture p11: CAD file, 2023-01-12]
cases/HW/middle.dxf
144.6 x 118.4

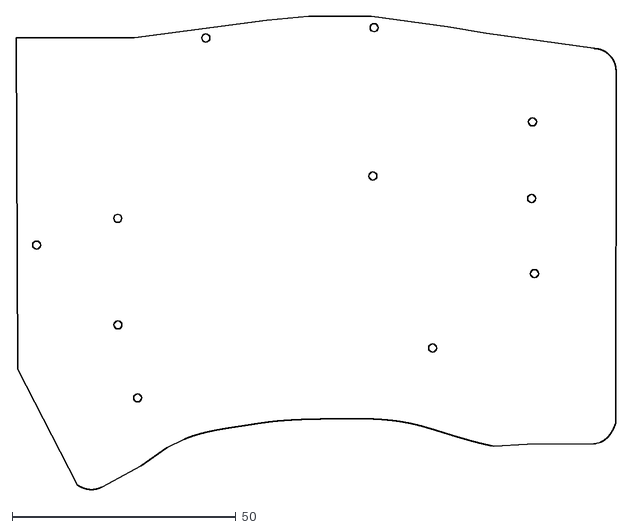
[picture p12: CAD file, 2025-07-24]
cases/choc/v1/chastity-bottom-right.dxf
134.0 x 105.7

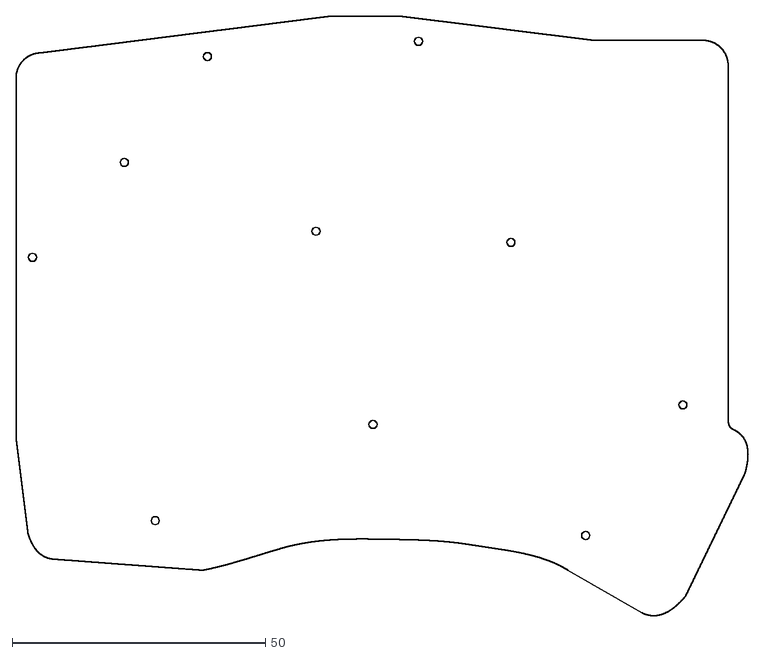
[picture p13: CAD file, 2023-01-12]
cases/HW/bottom.dxf
144.6 x 118.4

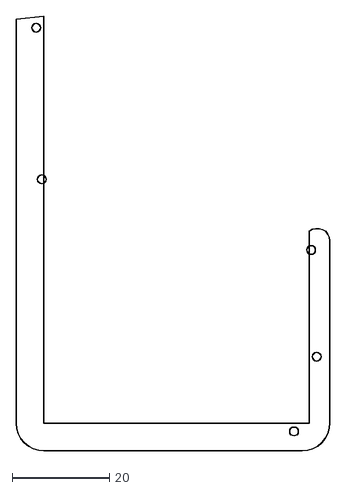
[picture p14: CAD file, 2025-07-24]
cases/choc/v1/chastity-bb-left.dxf
64.5 x 89.3

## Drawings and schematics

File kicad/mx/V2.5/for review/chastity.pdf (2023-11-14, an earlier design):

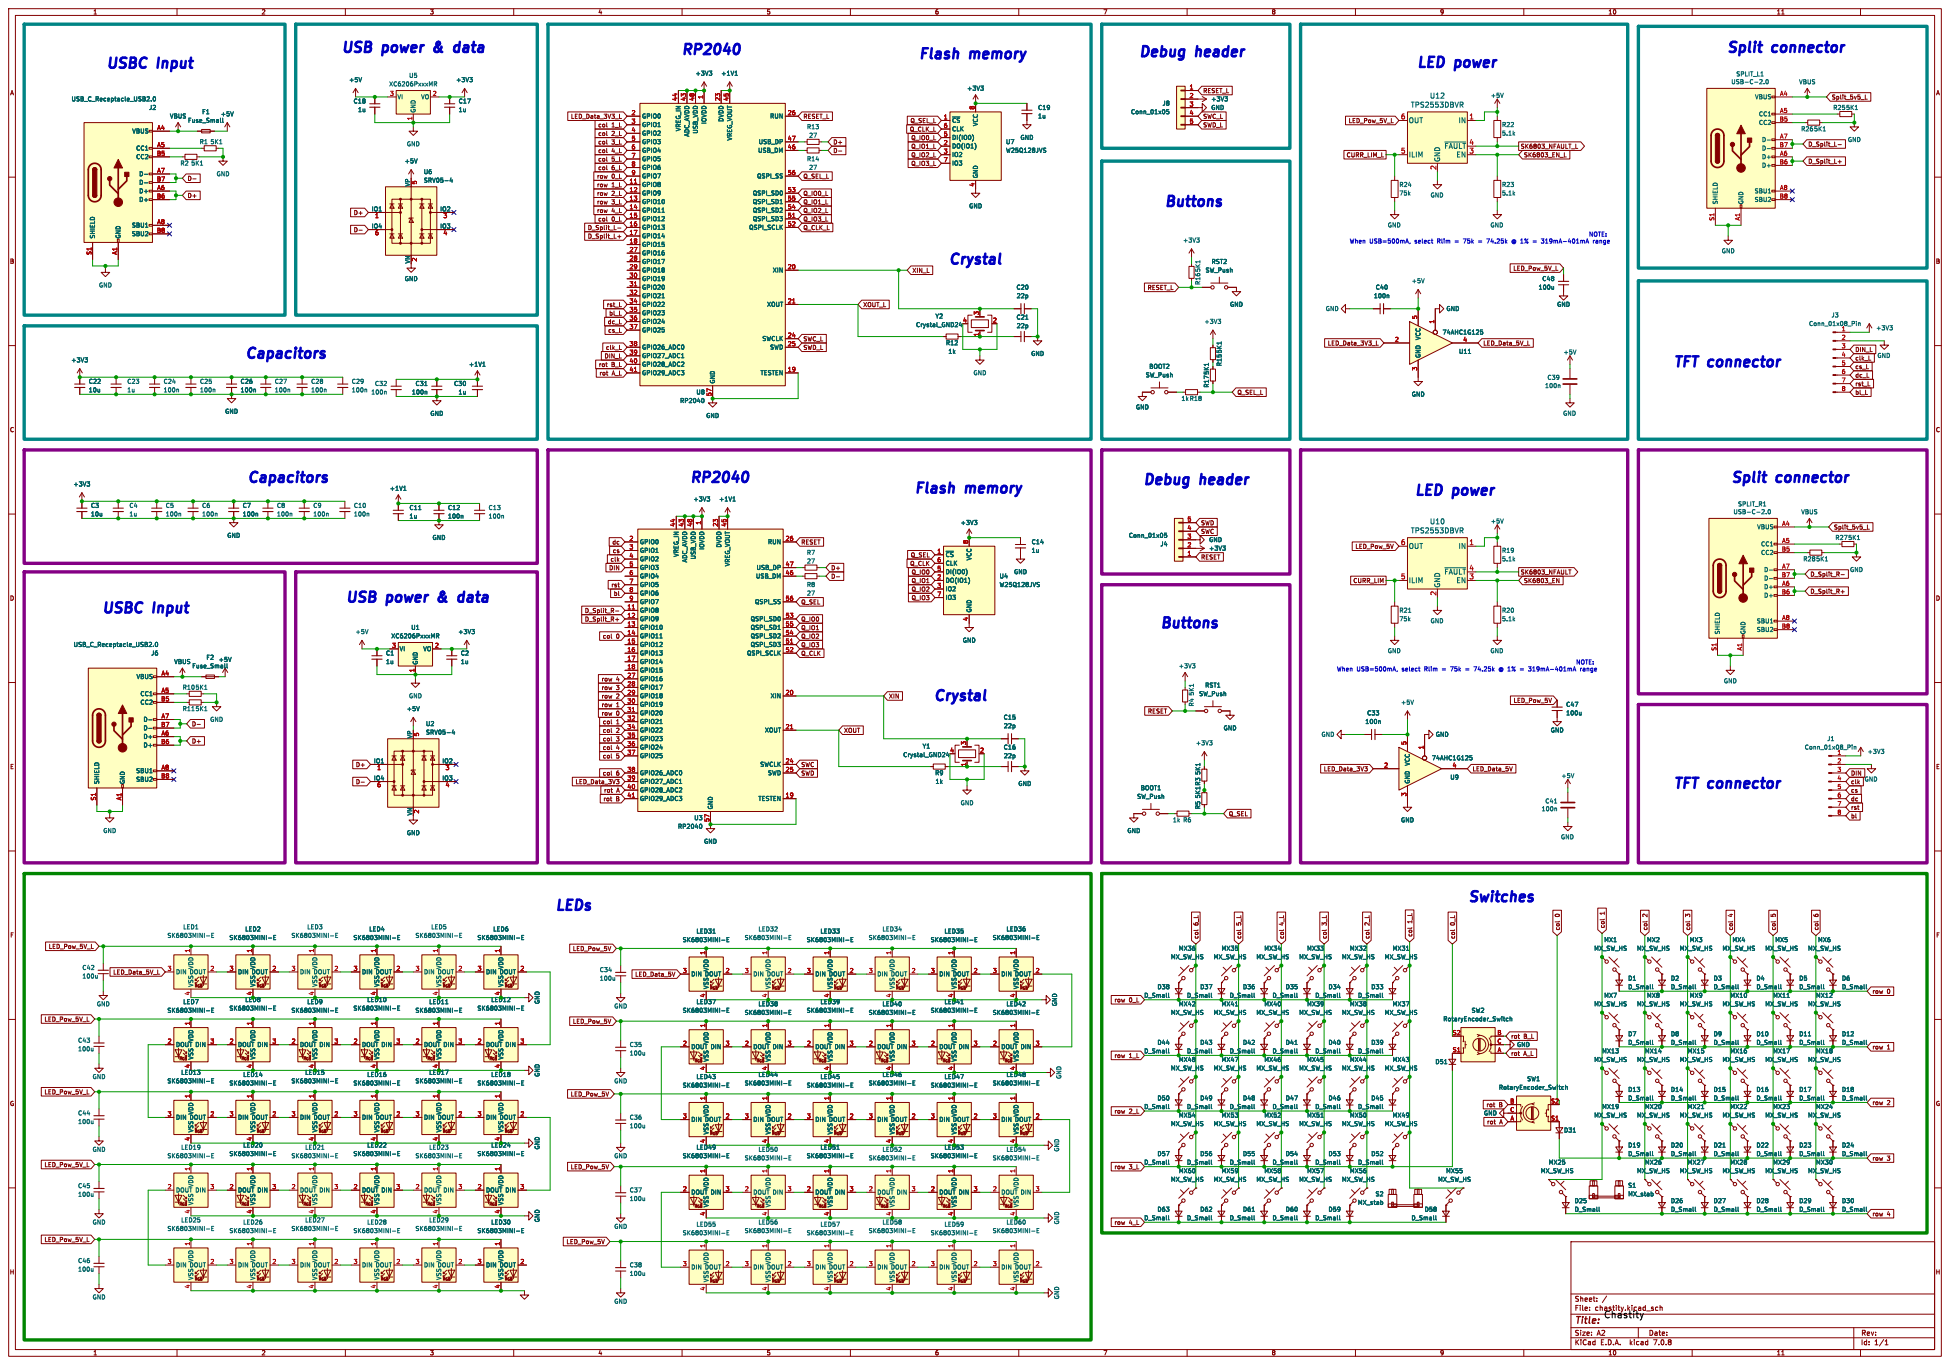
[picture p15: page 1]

1 GPIO8 11 GPIO9 12 GPIO10 13 GPIO11 14 GPIO12 15 GPIO13 16 GPIO14 17 GPIO15 18 TESTEN 19 GPIO0 2 XIN 20 XOUT 21 DVDD 23 SWCLK 24 SWD 25 RUN 26 GPIO16 27 GPIO17 28 GPIO18 29 GPIO1 3 GPIO19 30 GPIO20 31 GPIO21 32 GPIO22 34 GPIO23 35 GPIO24 36 GPIO25 37 GPIO26_ADC0 38 GPIO27_ADC1 39 GPIO2 4 GPIO28_ADC2 40 GPIO29_ADC3 41 ADC_AVDD 43 VREG_IN 44 VREG_VOUT 45 USB_DM 46 USB_DP 47 USB_VDD 48 GPIO3 5 QSPI_SD3 51 QSPI_SCLK 52 QSPI_SD0 53 QSPI_SD2 54 QSPI_SD1 55 QSPI_SS 56 GND 57 GPIO4 6 GPIO5 7 GPIO6 8 GPIO7 9 +1V1 +3V3 C19

1 GPIO8 11 GPIO9 12 GPIO10 13 GPIO11 14 GPIO12 15 GPIO13 16 GPIO14 17 GPIO15 18 TESTEN 19 GPIO0 2 XIN 20 XOUT 21 DVDD 23 SWCLK 24 SWD 25 RUN 26 GPIO16 27 GPIO17 28 GPIO18 29 GPIO1 3 GPIO19 30 GPIO20 31 GPIO21 32 GPIO22 34 GPIO23 35 GPIO24 36 GPIO25 37 GPIO26_ADC0 38 GPIO27_ADC1 39 GPIO2 4 GPIO28_ADC2 40 GPIO29_ADC3 41 ADC_AVDD 43 VREG_IN 44 VREG_VOUT 45 USB_DM 46 USB_DP 47 USB_VDD 48 GPIO3 5 QSPI_SD3 51 QSPI_SCLK 52 QSPI_SD0 53 QSPI_SD2 54 QSPI_SD1 55 QSPI_SS 56 GND 57 GPIO4 6 GPIO5 7 GPIO6 8 GPIO7 9 U8 RP2040 GND

1 GPIO8 11 GPIO9 12 GPIO10 13 GPIO11 14 GPIO12 15 GPIO13 16 GPIO14 17 GPIO15 18 TESTEN 19 GPIO0 2 XIN 20 XOUT 21 DVDD 23 SWCLK 24 SWD 25 RUN 26 GPIO16 27 GPIO17 28 GPIO18 29 GPIO1 3 GPIO19 30 GPIO20 31 GPIO21 32 GPIO22 34 GPIO23 35 GPIO24 36 GPIO25 37 GPIO26_ADC0 38 GPIO27_ADC1 39 GPIO2 4 GPIO28_ADC2 40 GPIO29_ADC3 41 ADC_AVDD 43 VREG_IN 44 VREG_VOUT 45 USB_DM 46 USB_DP 47 USB_VDD 48 GPIO3 5 QSPI_SD3 51 QSPI_SCLK 52 QSPI_SD0 53 QSPI_SD2 54 QSPI_SD1 55 QSPI_SS 56 GND 57 GPIO4 6 GPIO5 7 GPIO6 8 GPIO7 9 +3V3 +1V1 +3V3 Y1 Crystal_GND24

1 GPIO8 11 GPIO9 12 GPIO10 13 GPIO11 14 GPIO12 15 GPIO13 16 GPIO14 17 GPIO15 18 TESTEN 19 GPIO0 2 XIN 20 XOUT 21 DVDD 23 SWCLK 24 SWD 25 RUN 26 GPIO16 27 GPIO17 28 GPIO18 29 GPIO1 3 GPIO19 30 GPIO20 31 GPIO21 32 GPIO22 34 GPIO23 35 GPIO24 36 GPIO25 37 GPIO26_ADC0 38 GPIO27_ADC1 39 GPIO2 4 GPIO28_ADC2 40 GPIO29_ADC3 41 ADC_AVDD 43 VREG_IN 44 VREG_VOUT 45 USB_DM 46 USB_DP 47 USB_VDD 48 GPIO3 5 QSPI_SD3 51 QSPI_SCLK 52 QSPI_SD0 53 QSPI_SD2 54 QSPI_SD1 55 QSPI_SS 56 GND 57 GPIO4 6 GPIO5 7 GPIO6 8 GPIO7 9 U3 RP2040 R8

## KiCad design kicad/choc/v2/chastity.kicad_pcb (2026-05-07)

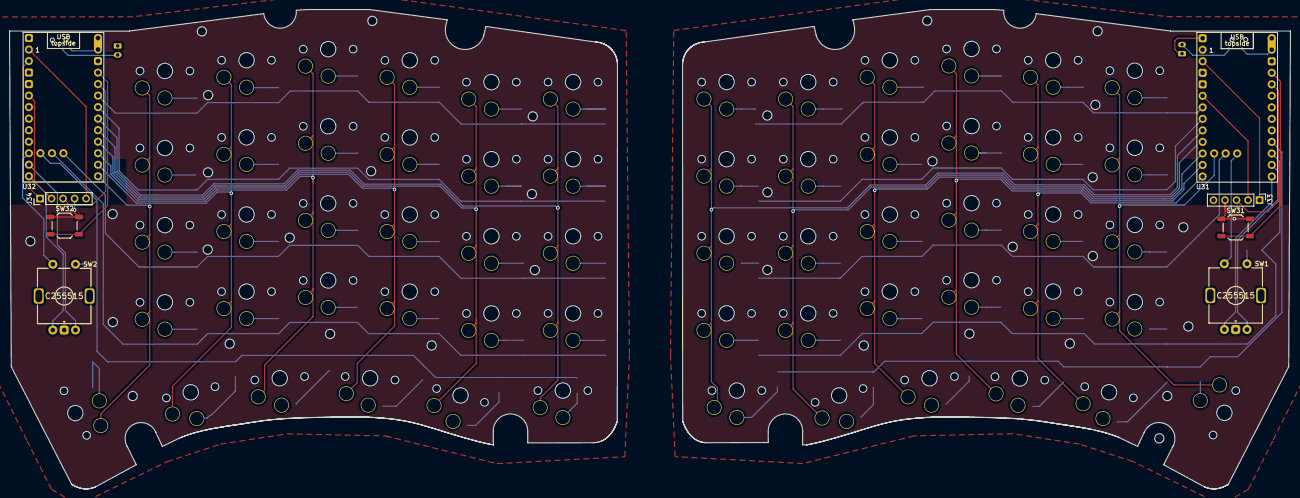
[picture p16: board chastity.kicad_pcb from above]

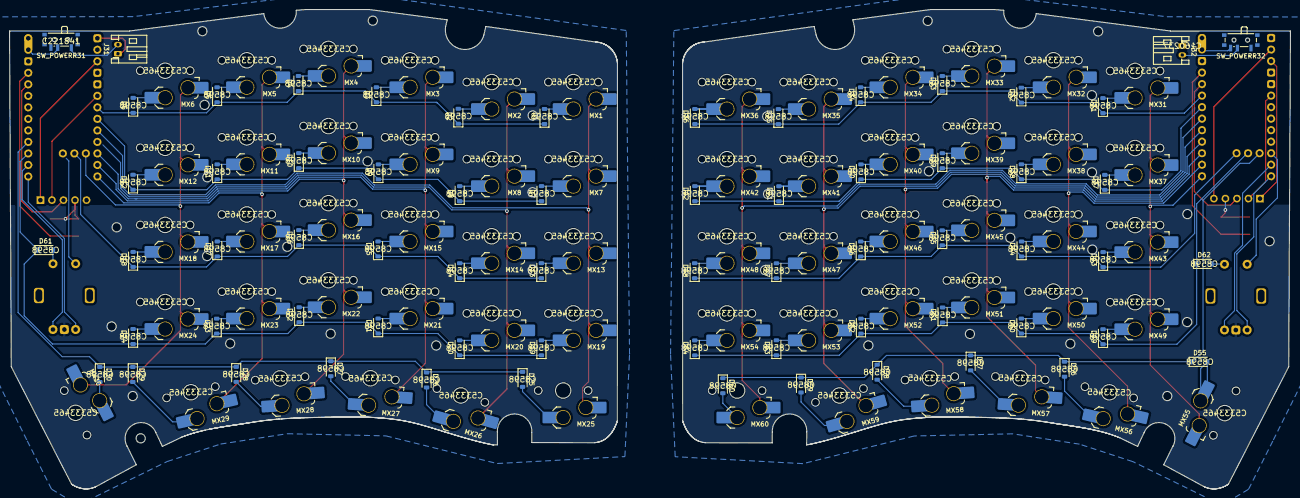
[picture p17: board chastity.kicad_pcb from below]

Board: 2 copper layers, 282.4 x 105.7 mm, 134 parts (126 on the bottom side), 107 nets.

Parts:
D1, D2, D3, D4, D5, D6, D7, D8, D9, D10, D11, D12, D13, D14, D15, D16, D17, D18, D19, D20, D21, D22, D23, D24, D25, D26, D27, D28, D29, D30, D31, D32, D33, D34, D35, D36, D37, D38, D39, D40, D41, D42, D43, D44, D45, D46, D47, D48, D49, D50, D51, D52, D53, D54, D55, D56, D57, D58, D59, D60, D61, D62: D_Small; D_SOD-123
J31, J32: Conn_01x02_Socket; JST_PH_S2B-PH-K_1x02_P2.00mm_Horizontal
J33, J34: Conn_01x05_Socket; PinHeader_1x05_P2.54mm_Vertical
MX1, MX2, MX3, MX4, MX5, MX6, MX7, MX8, MX9, MX10, MX11, MX12, MX13, MX14, MX15, MX16, MX17, MX18, MX19, MX20, MX21, MX22, MX23, MX24, MX26, MX27, MX28, MX29, MX30, MX31, MX32, MX33, MX34, MX35, MX36, MX37, MX38, MX39, MX40, MX41, MX42, MX43, MX44, MX45, MX46, MX47, MX48, MX49, MX50, MX51, MX52, MX53, MX54, MX55, MX56, MX57, MX58, MX59: MX_SW_HS; SW_choc_v1_HS_CPG135001S30_1u
MX25, MX60: MX_SW_HS; SW_choc_v1_HS_CPG135001S30_1.25u
SW1, SW2: RotaryEncoder_Switch; ROT_Alps_EC11E-Switch
SW31, SW32: SW_Push; SW_SPST_TL3342
SW_POWERR31, SW_POWERR32: SW_SPDT; SW_SPDT_PCM12
U31, U32: nice_nano; nice_nano_AH_USBup

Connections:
GND: J33.4, J34.4, SW1.C, SW2.C, SW31.1, SW32.1
unnamed: D1.2 (A), MX1.2
unnamed: D2.2 (A), MX2.2
unnamed: D3.2 (A), MX3.2
unnamed: D4.2 (A), MX4.2
unnamed: D5.2 (A), MX5.2
unnamed: D6.2 (A), MX6.2
unnamed: D7.2 (A), MX7.2
unnamed: D8.2 (A), MX8.2
unnamed: D9.2 (A), MX9.2
unnamed: D10.2 (A), MX10.2
unnamed: D11.2 (A), MX11.2
unnamed: D12.2 (A), MX12.2
unnamed: D13.2 (A), MX13.2
unnamed: D14.2 (A), MX14.2
unnamed: D15.2 (A), MX15.2
unnamed: D16.2 (A), MX16.2
unnamed: D17.2 (A), MX17.2
unnamed: D18.2 (A), MX18.2
unnamed: D19.2 (A), MX19.2
unnamed: D20.2 (A), MX20.2
unnamed: D21.2 (A), MX21.2
unnamed: D22.2 (A), MX22.2
unnamed: D23.2 (A), MX23.2
unnamed: D24.2 (A), MX24.2
unnamed: D25.2 (A), MX25.2
unnamed: D26.2 (A), MX26.2
unnamed: D27.2 (A), MX27.2
unnamed: D28.2 (A), MX28.2
unnamed: D29.2 (A), MX29.2
unnamed: D30.2 (A), MX30.2
unnamed: D31.2 (A), MX31.2
unnamed: D32.2 (A), MX32.2
unnamed: D33.2 (A), MX33.2
unnamed: D34.2 (A), MX34.2
unnamed: D35.2 (A), MX35.2
unnamed: D36.2 (A), MX36.2
unnamed: D37.2 (A), MX37.2
unnamed: D38.2 (A), MX38.2
unnamed: D39.2 (A), MX39.2
unnamed: D40.2 (A), MX40.2
unnamed: D41.2 (A), MX41.2
unnamed: D42.2 (A), MX42.2
unnamed: D43.2 (A), MX43.2
unnamed: D44.2 (A), MX44.2
unnamed: D45.2 (A), MX45.2
unnamed: D46.2 (A), MX46.2
unnamed: D47.2 (A), MX47.2
unnamed: D48.2 (A), MX48.2
unnamed: D49.2 (A), MX49.2
unnamed: D50.2 (A), MX50.2
unnamed: D51.2 (A), MX51.2
unnamed: D52.2 (A), MX52.2
unnamed: D53.2 (A), MX53.2
unnamed: D54.2 (A), MX54.2
unnamed: D55.2 (A), MX55.2
unnamed: D56.2 (A), MX56.2
unnamed: D57.2 (A), MX57.2
unnamed: D58.2 (A), MX58.2
unnamed: D59.2 (A), MX59.2
unnamed: D60.2 (A), MX60.2
unnamed: D61.2 (A), SW1.S1
unnamed: D62.2 (A), SW2.S1
unnamed: J31.1, U31.28 (GND)
unnamed: J31.2, SW_POWERR31.1 (A)
unnamed: J32.1, U32.28 (GND)
unnamed: J32.2, SW_POWERR32.2 (B)
unnamed: J33.3, U31.16 (3V3)
unnamed: J34.3, U32.16 (3V3)
unnamed: SW_POWERR31.2 (B), U31.13 (BAT+)
unnamed: SW_POWERR32.3 (C), U32.13 (BAT+)
unnamed: SW31.2, U31.15 (RST)
unnamed: SW32.2, U32.15 (RST)
SCLK: J33.2, U31.5 (P0.17)
SCLK_R: J34.2, U32.5 (P0.17)
SCS: J33.5, U31.1 (P0.06)
SCS_R: J34.5, U32.1 (P0.06)
SI: J33.1, U31.2 (P0.08)
SI_R: J34.1, U32.2 (P0.08)
col 0: SW2.S2, U32.10 (P0.11)
col 1: MX31.1, MX37.1, MX43.1, MX49.1, MX55.1, U32.24 (P0.09-LF)
col 2: MX32.1, MX38.1, MX44.1, MX50.1, MX56.1, U32.23 (P0-10-LF)
col 3: MX33.1, MX39.1, MX45.1, MX51.1, MX57.1, U32.22 (P1.11-LF)
col 4: MX34.1, MX40.1, MX46.1, MX52.1, MX58.1, U32.21 (P1.13-LF)
col 5: MX35.1, MX41.1, MX47.1, MX53.1, MX59.1, U32.20 (P1.15-LF)
col 6: MX36.1, MX42.1, MX48.1, MX54.1, MX60.1, U32.19 (P0.02-LF)
col_0_l: SW1.S2, U31.27 (P1-07-LF)
col_1_l: MX6.1, MX12.1, MX18.1, MX24.1, MX30.1, U31.25 (P1.01-LF)
col_2_l: MX5.1, MX11.1, MX17.1, MX23.1, MX29.1, U31.12 (P1.06-LF)
col_3_l: MX4.1, MX10.1, MX16.1, MX22.1, MX28.1, U31.11 (P1.04-LF)
col_4_l: MX3.1, MX9.1, MX15.1, MX21.1, MX27.1, U31.10 (P0.11)
col_5_l: MX2.1, MX8.1, MX14.1, MX20.1, MX26.1, U31.9 (P1.00)
col_6_l: MX1.1, MX7.1, MX13.1, MX19.1, MX25.1, U31.8 (P0.24)
rot_a: SW2.A, U32.12 (P1.06-LF)
rot_a_l: SW1.A, U31.24 (P0.09-LF)
rot_b: SW2.B, U32.11 (P1.04-LF)
rot_b_l: SW1.B, U31.23 (P0-10-LF)
row_0: D55.1 (K), D56.1 (K), D57.1 (K), D58.1 (K), D59.1 (K), D60.1 (K), U32.25 (P1.01-LF)
row_0_l: D25.1 (K), D26.1 (K), D27.1 (K), D28.1 (K), D29.1 (K), D30.1 (K), U31.21 (P1.13-LF)
row_1: D49.1 (K), D50.1 (K), D51.1 (K), D52.1 (K), D53.1 (K), D54.1 (K), D62.1 (K), U32.26 (P1.02-LF)
row_1_l: D19.1 (K), D20.1 (K), D21.1 (K), D22.1 (K), D23.1 (K), D24.1 (K), D61.1 (K), U31.22 (P1.11-LF)
row_2: D43.1 (K), D44.1 (K), D45.1 (K), D46.1 (K), D47.1 (K), D48.1 (K), U32.27 (P1-07-LF)
row_2_l: D13.1 (K), D14.1 (K), D15.1 (K), D16.1 (K), D17.1 (K), D18.1 (K), U31.26 (P1.02-LF)
row_3: D37.1 (K), D38.1 (K), D39.1 (K), D40.1 (K), D41.1 (K), D42.1 (K), U32.18 (P0.29-LF)
row_3_l: D7.1 (K), D8.1 (K), D9.1 (K), D10.1 (K), D11.1 (K), D12.1 (K), U31.7 (P0.22)
row_4: D31.1 (K), D32.1 (K), D33.1 (K), D34.1 (K), D35.1 (K), D36.1 (K), U32.17 (P0.31-LF)
row_4_l: D1.1 (K), D2.1 (K), D3.1 (K), D4.1 (K), D5.1 (K), D6.1 (K), U31.6 (P0.20)

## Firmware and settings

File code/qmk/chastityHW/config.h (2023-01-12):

#pragma once

/* USB Device descriptor parameter */
#define VENDOR_ID       0xFC32
#define PRODUCT_ID      0x0287
#define DEVICE_VER      0x0001
#define MANUFACTURER    streetRAT
#define PRODUCT         Chastity

/* key matrix size */
// Rows are doubled-up
#define MATRIX_ROWS 10
#define MATRIX_COLS  7

// wiring of each half
#define MATRIX_ROW_PINS { D4, C6, D7, E6, B4 }
#define MATRIX_COL_PINS { B6, B2, B3, B1, F7, F6, B5 }
#define DIODE_DIRECTION COL2ROW

#define TAPPING_TERM 100
#define DEBOUNCE 5

/* encoder support */
#define ENCODERS_PAD_A { F5 }
#define ENCODERS_PAD_B { F4 }
#define ENCODERS_PAD_A_RIGHT { F4 }
#define ENCODERS_PAD_B_RIGHT { F5 }
#define ENCODER_RESOLUTION 2

#define TAP_CODE_DELAY 10

/* communication between sides */
#define USE_SERIAL
#define SERIAL_USE_MULTI_TRANSACTION
#define SOFT_SERIAL_PIN D2

#define NO_ACTION_MACRO
#define NO_ACTION_FUNCTION

/* Use 1000hz polling */
#define USB_POLLING_INTERVAL_MS 1

#define VIAL_COMBO_ENTRIES 4

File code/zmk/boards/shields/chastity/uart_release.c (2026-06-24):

#include <zephyr/init.h>
#include <hal/nrf_uarte.h>
#include <cmsis_core.h>

/* Force UICR.NFCPINS to GPIO mode if it's still in NFC mode, releasing
 * P0.09 (NFC1) and P0.10 (NFC2). Zephyr's boot-time SoC code is supposed
 * to do this when nfct-pins-as-gpios is set in DT, but on these MCUs it
 * apparently isn't taking effect (intermittent ] / 1 spam survives the
 * standard flow). Programming UICR directly here is identical to what
 * Zephyr does internally; UICR change requires a soft reset to apply. */
static void chastity_program_nfc_uicr(void)
{
	if ((NRF_UICR->NFCPINS & UICR_NFCPINS_PROTECT_Msk) !=
	    (UICR_NFCPINS_PROTECT_Disabled << UICR_NFCPINS_PROTECT_Pos)) {
		NRF_NVMC->CONFIG = NVMC_CONFIG_WEN_Wen << NVMC_CONFIG_WEN_Pos;
		while (NRF_NVMC->READY == NVMC_READY_READY_Busy) {
		}
		NRF_UICR->NFCPINS &= ~UICR_NFCPINS_PROTECT_Msk;
		while (NRF_NVMC->READY == NVMC_READY_READY_Busy) {
		}
		NRF_NVMC->CONFIG = NVMC_CONFIG_WEN_Ren << NVMC_CONFIG_WEN_Pos;
		while (NRF_NVMC->READY == NVMC_READY_READY_Busy) {
		}
		NVIC_SystemReset();
	}
}

/* The Adafruit nice!nano bootloader leaves UARTE0 enabled with
 * PSEL.TXD=P0.06 and PSEL.RXD=P0.08. With uart0 status="disabled" in DT,
 * the Zephyr UART driver never runs and never clears that hold — so kscan
 * can't drive P0.06/P0.08, which is why right-half cols 8 and 9 are silent.
 * Run this before any driver init to force UARTE0 off and free its pins. */
static int chastity_release_uart_pins(void)
{
	chastity_program_nfc_uicr();
	nrf_uarte_disable(NRF_UARTE0);
	nrf_uarte_txrx_pins_disconnect(NRF_UARTE0);
	nrf_uarte_hwfc_pins_disconnect(NRF_UARTE0);
	return 0;
}

SYS_INIT(chastity_release_uart_pins, PRE_KERNEL_1, 50);

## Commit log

2023-11-14 added TFT and centered master USBC
    The case also got changed to accept the new TFT
    [chastity.kicad_sch]
2025-07-24 updated files to store all my work
    [BOM-chastity.csv, bom.csv, bottom.dxf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]
2026-05-07 house keeping
    [chastity.kicad_pcb]
2026-05-08 working no encoder
